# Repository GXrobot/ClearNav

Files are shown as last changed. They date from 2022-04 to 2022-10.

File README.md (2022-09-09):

GitHub Repository for Capstone Project of ClearNav Team
```
Members Include:
Spencer Lall
William Xue
Muhammad Ahmed Ather
William Huong
Namsakhi Kumar
Taimoor Ahmed
```

Spring - Summer 2022 Engineering Science Capstone Project

EZhud is a convenient heads up display motorcycle riders that features
built-in navigation, speed limit display and helmet mounted dashcam.

In this repository contains the code for the webserver, raspberry pi internal scripts
3D printed designs and GPS tracking code. 

EZhud is easy to use and and presents a simple interface for the user. Any information is presented in a heads up display above the riders right eye.

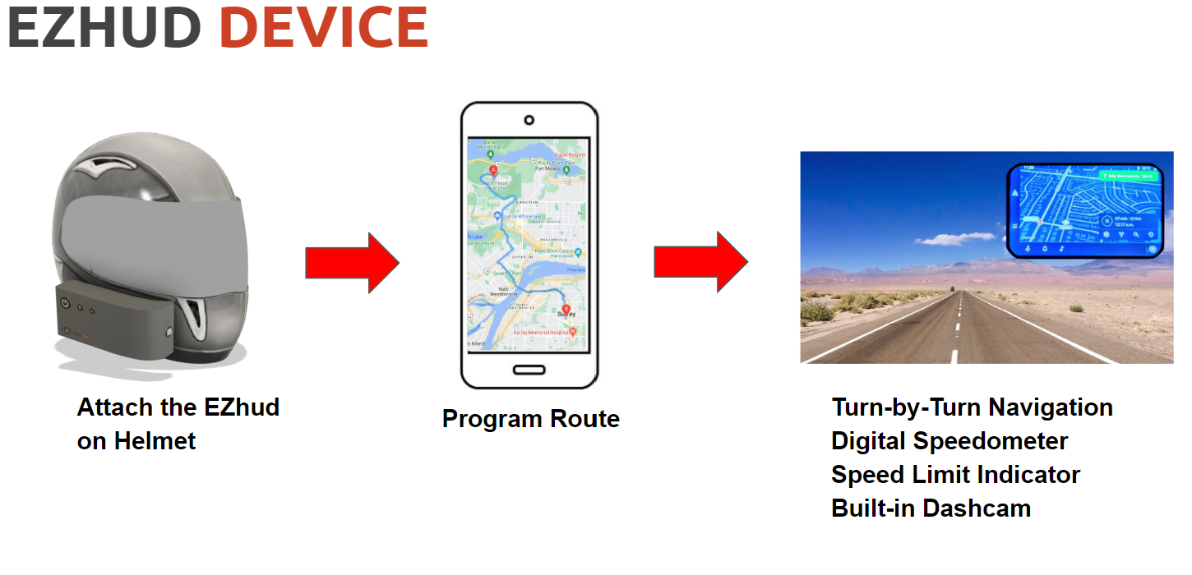
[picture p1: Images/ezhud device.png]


The following image shows the system overview of the EZhud device.

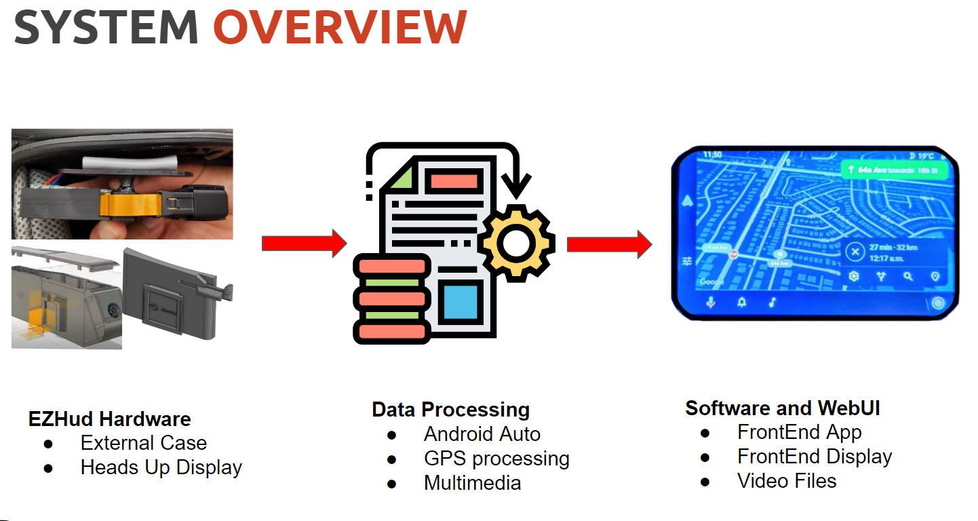
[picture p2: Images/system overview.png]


Here is a final product image on a full-face helmet.

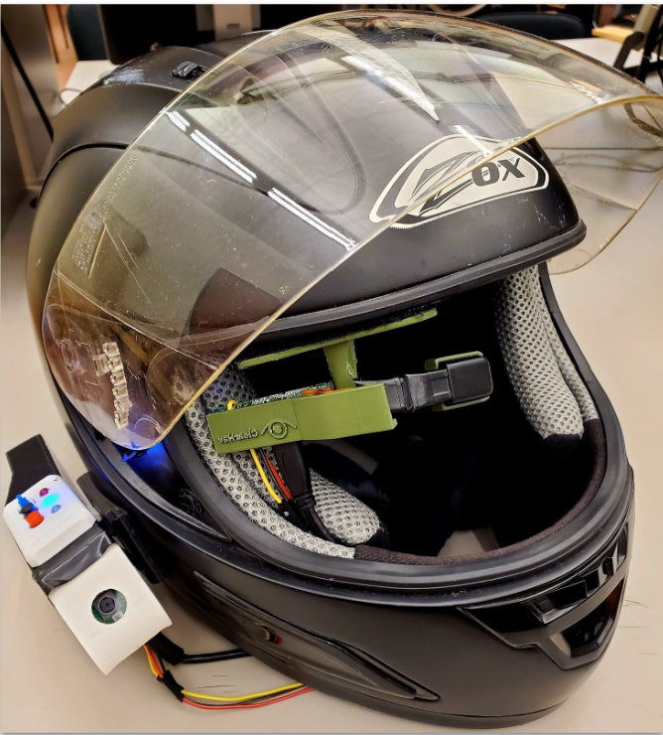
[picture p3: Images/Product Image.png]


The following is the Youtube video of the project.

IMAGE ALT TEXT HERE (https://www.youtube.com/watch?v=_HTLBEL7PS4)

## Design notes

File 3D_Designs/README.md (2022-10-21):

This folder contains all the 3D design in the EZhud project

Lead by: William Xue

- Vufine Holder (Balljoint Top.step)
```
Contains a 2 part design, main part attached to the upper lip of the helmet, 
display part attached with a ball joint to the main part. This allows the user to 
adjust the display angle of the device
```
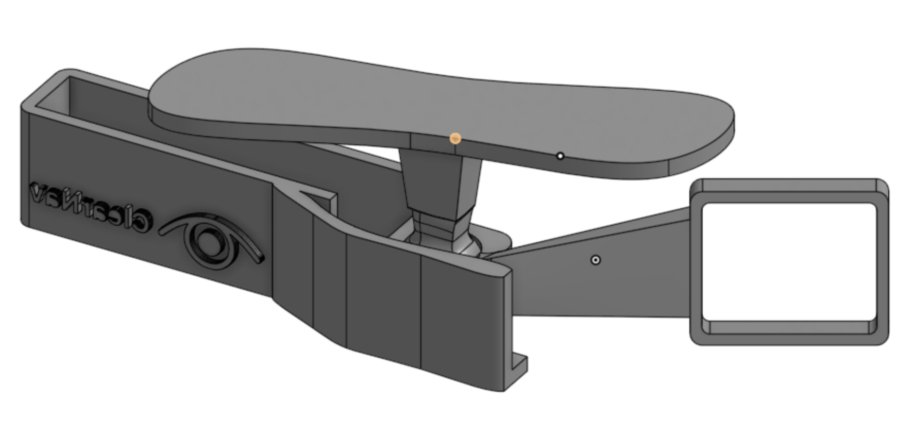
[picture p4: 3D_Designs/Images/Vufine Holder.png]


- Main Body (Body Design v166.step)
```
Contains the main body of the device, including the dashcam, battery, raspberry pi cm4 board and the GPS
a powerboost (DC-DC boost) is also included
```
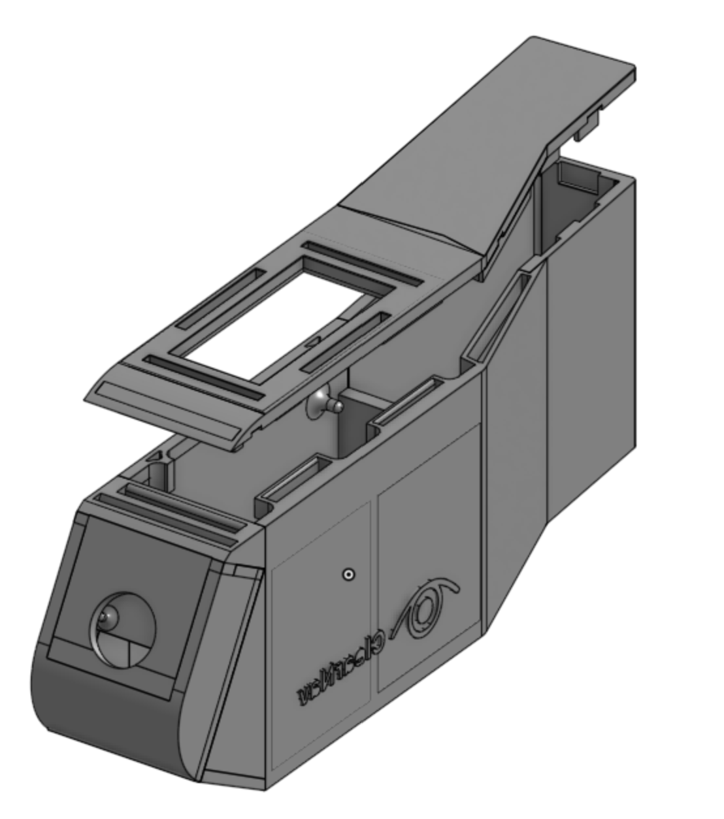
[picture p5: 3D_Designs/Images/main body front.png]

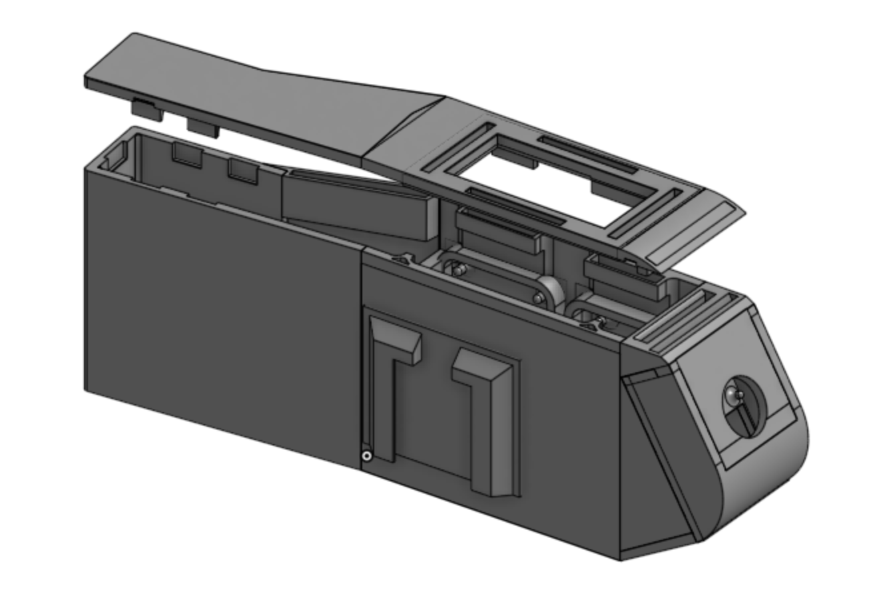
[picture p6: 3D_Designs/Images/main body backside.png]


- Helmet Attach V2 (HelmetAttachV2.step)
```
The concave side connects to the helmet via 3M VHB (very high bond tape), and the other side attaches to the main body
A locking pin is also included to keep the main body in place.
Attaches to majority of full face helmets as well as half face helmets
```

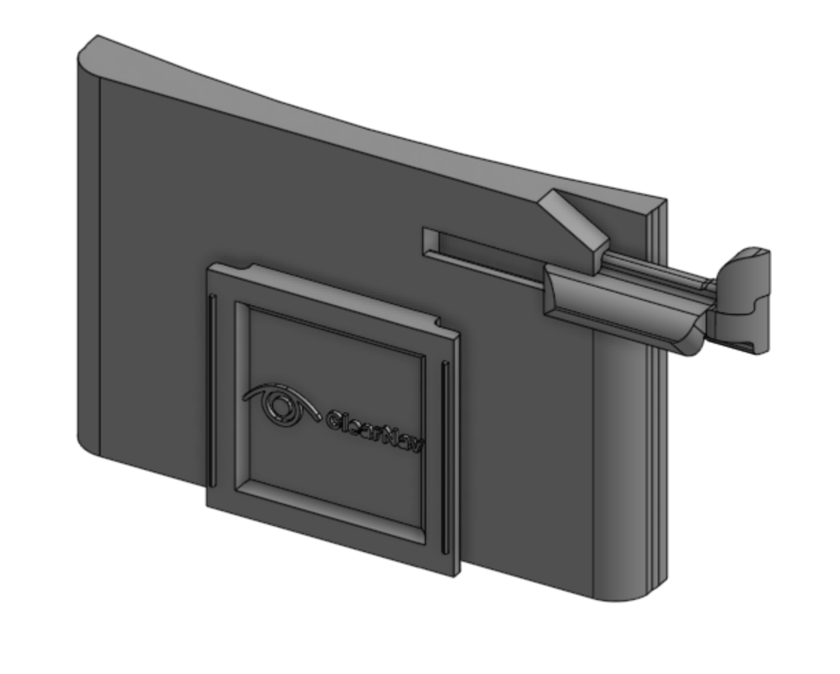
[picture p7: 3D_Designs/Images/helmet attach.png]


- Button Board (Button Board.step)
```
The board contains a cover for tactile switches and latching switches, the main interface to our device.
```

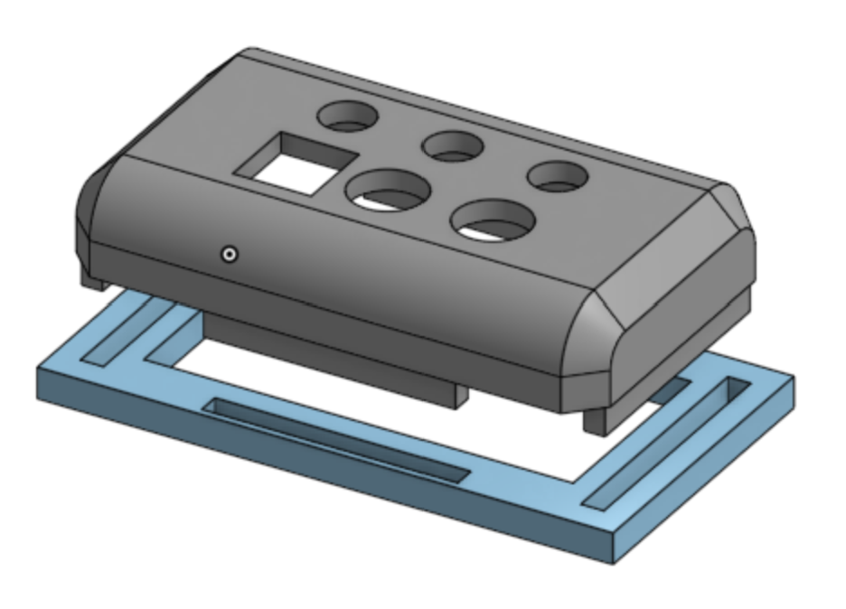
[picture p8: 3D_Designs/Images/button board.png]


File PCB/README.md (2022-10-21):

PCB Design for EZhud Motorcycle Project

```
Lead by:
Muhammad Ahmed Ather
Taimoor Ahmed
```

PCB design is compact and meant to be connected to the Raspberry Pi CM4 board, featuring
all the ports necessary for our project. Including RPi CM4 Hirose connectors, high speed USB,
SD card slot, GPIO connectors, mini-HDMI connector, USB-C power connector and the RPi Cam
interface

Work is still in progress! PCB still needs some tweaking to be fully functional. 

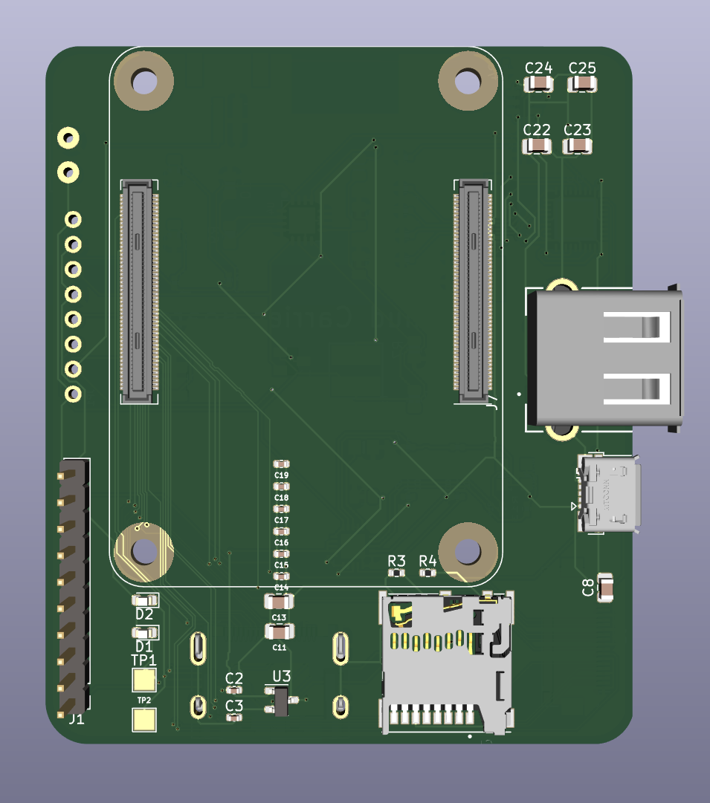
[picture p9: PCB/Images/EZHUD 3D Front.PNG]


This image shows the front of the PCB design.

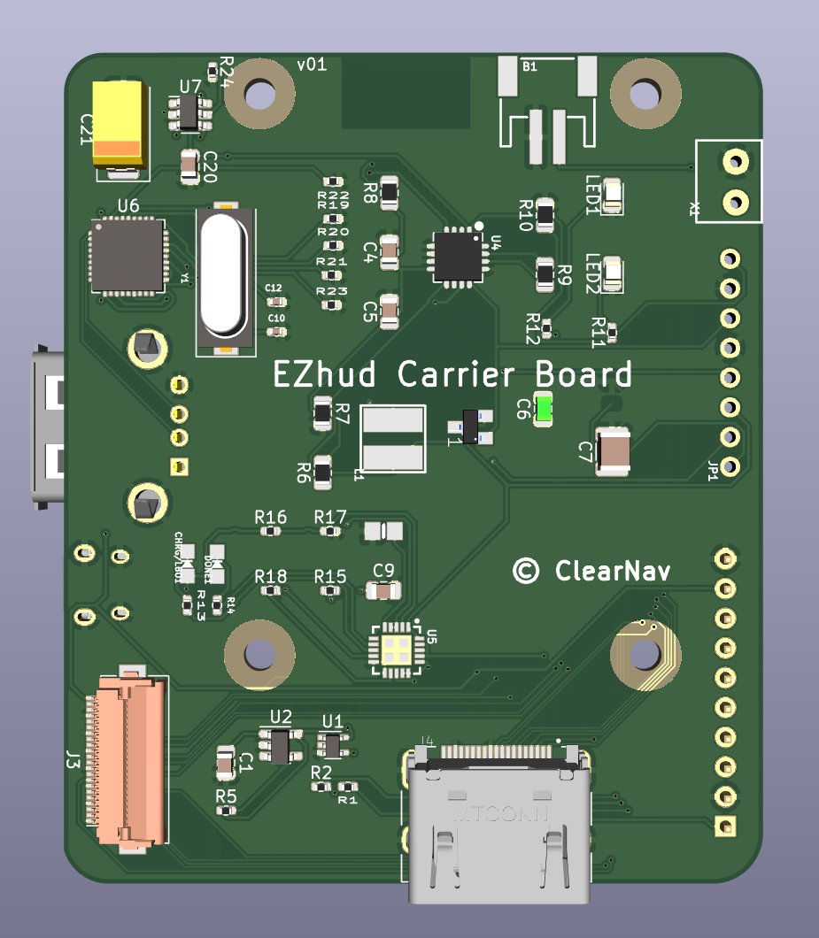
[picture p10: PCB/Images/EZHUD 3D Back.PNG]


This image shows the back of the PCB design.

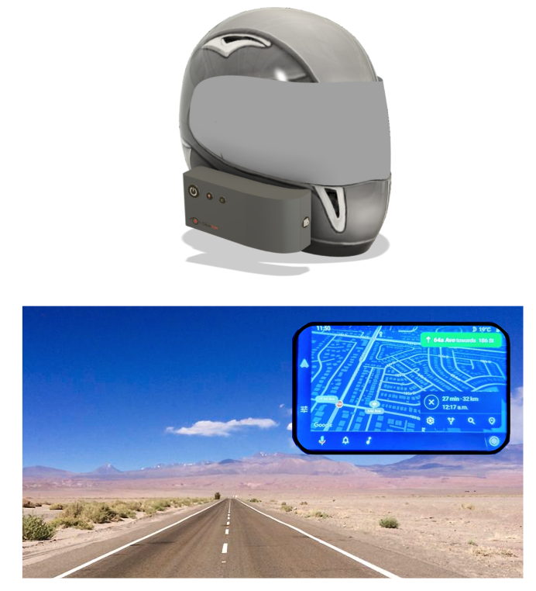
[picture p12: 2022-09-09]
Images/the solution.png

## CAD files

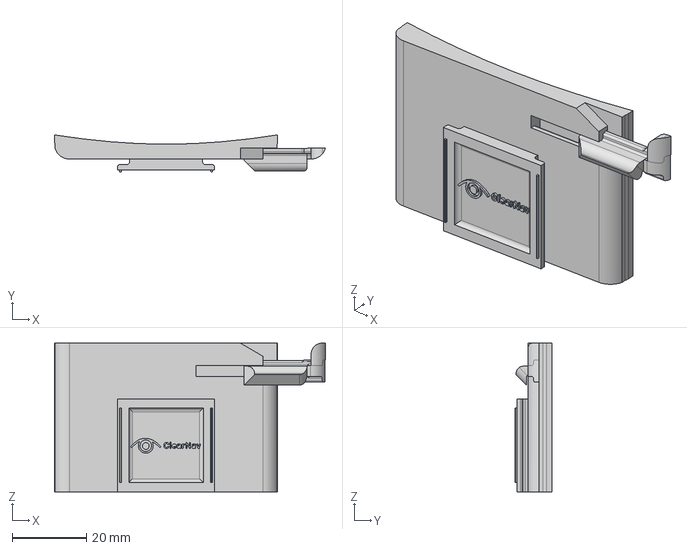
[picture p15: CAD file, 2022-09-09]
3D_Designs/HelmetAttachV2.step
72.9 x 10.0 x 40.0 mm

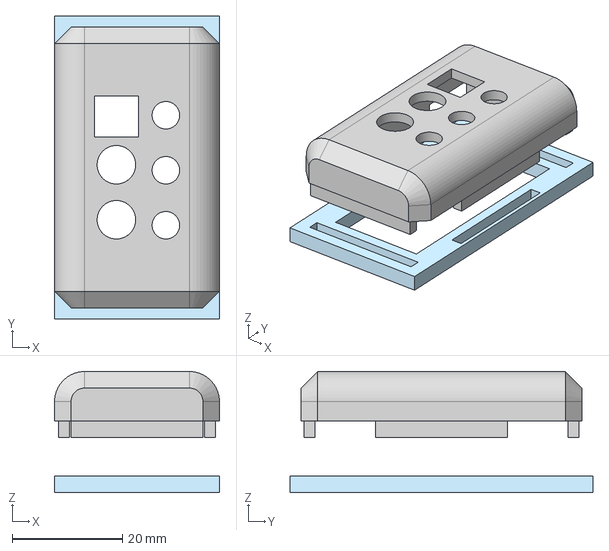
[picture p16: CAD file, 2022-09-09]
3D_Designs/Button Board.step
30.0 x 55.0 x 22.0 mm

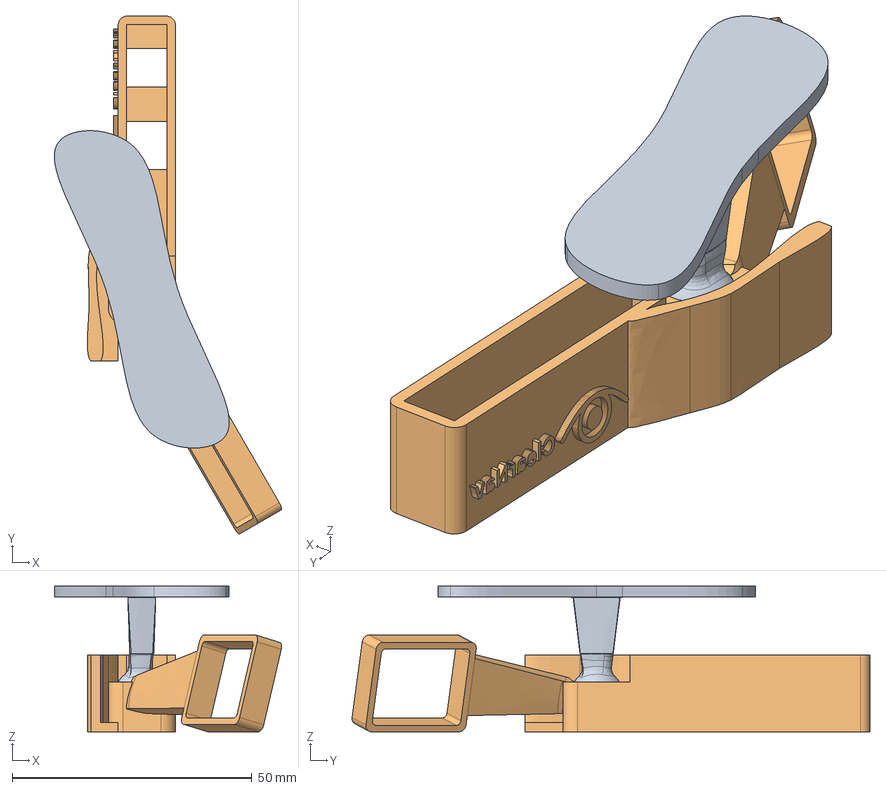
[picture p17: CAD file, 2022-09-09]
3D_Designs/Balljoint Top.step
47.4 x 107.9 x 30.4 mm

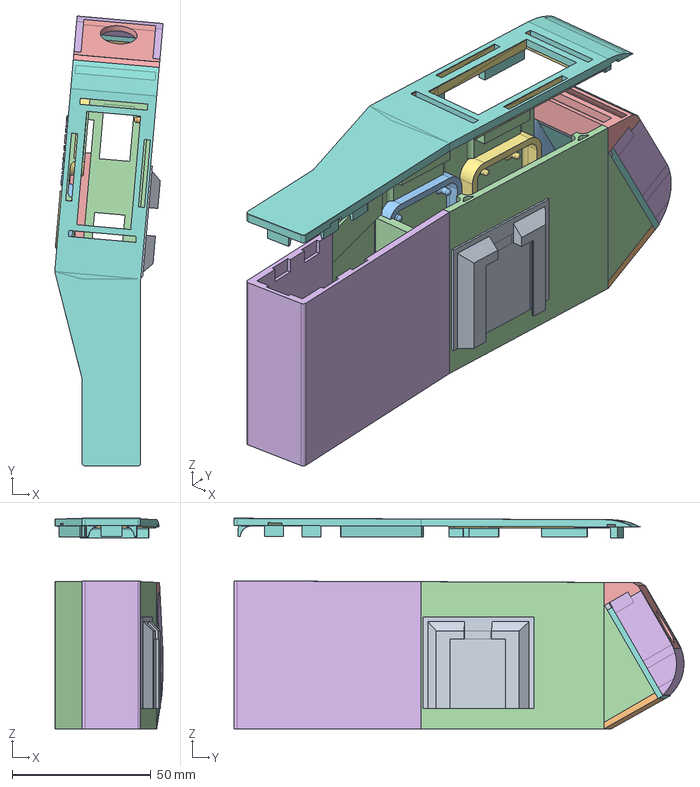
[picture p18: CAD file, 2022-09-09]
3D_Designs/Body Design v166.step
39.0 x 162.1 x 75.9 mm
Device Connector
CM4 Holder In Design
GPS Holder
Battery - CM4 Connector
Camera Holder
Powerboost Holder in Design
Camera Holder_1
Battery Holder
Button Board Bottom
Logo

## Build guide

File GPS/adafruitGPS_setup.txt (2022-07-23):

# upgrade packages
sudo apt update
sudo apt upgrade

# disable serial input/output interface
sudo raspi-config
--> disable login shell over serial
--> enable serial port hardware

# install adafruit gps python libary
pip3 install adafruit-circuitpython-gps

# get internet on pi
sudo iwlist wlan0 scan
sudo vim /etc/wpa_supplicant/wpa_supplicant.conf:

    ctrl_interface=DIR=/var/run/wpa_supplicant GROUP=netdev
    update_config=1
    country=CA

    network={
        ssid="You SSID Name"
        psk="Your WiFI Password"
        key_mgmt=WPA-PSK
    }

note: can view wpa_supplicant log messages using
    * sudo wpa_supplicant -c/etc/wpa_supplicant/wpa_supplicant.conf -iwlan0 -d

# install PySimpleGUI
pip3 install PySimpleGUI

# install tkinter
    --> note for mac (need to configure python 3 for tk): brew install python3-tk@3.9

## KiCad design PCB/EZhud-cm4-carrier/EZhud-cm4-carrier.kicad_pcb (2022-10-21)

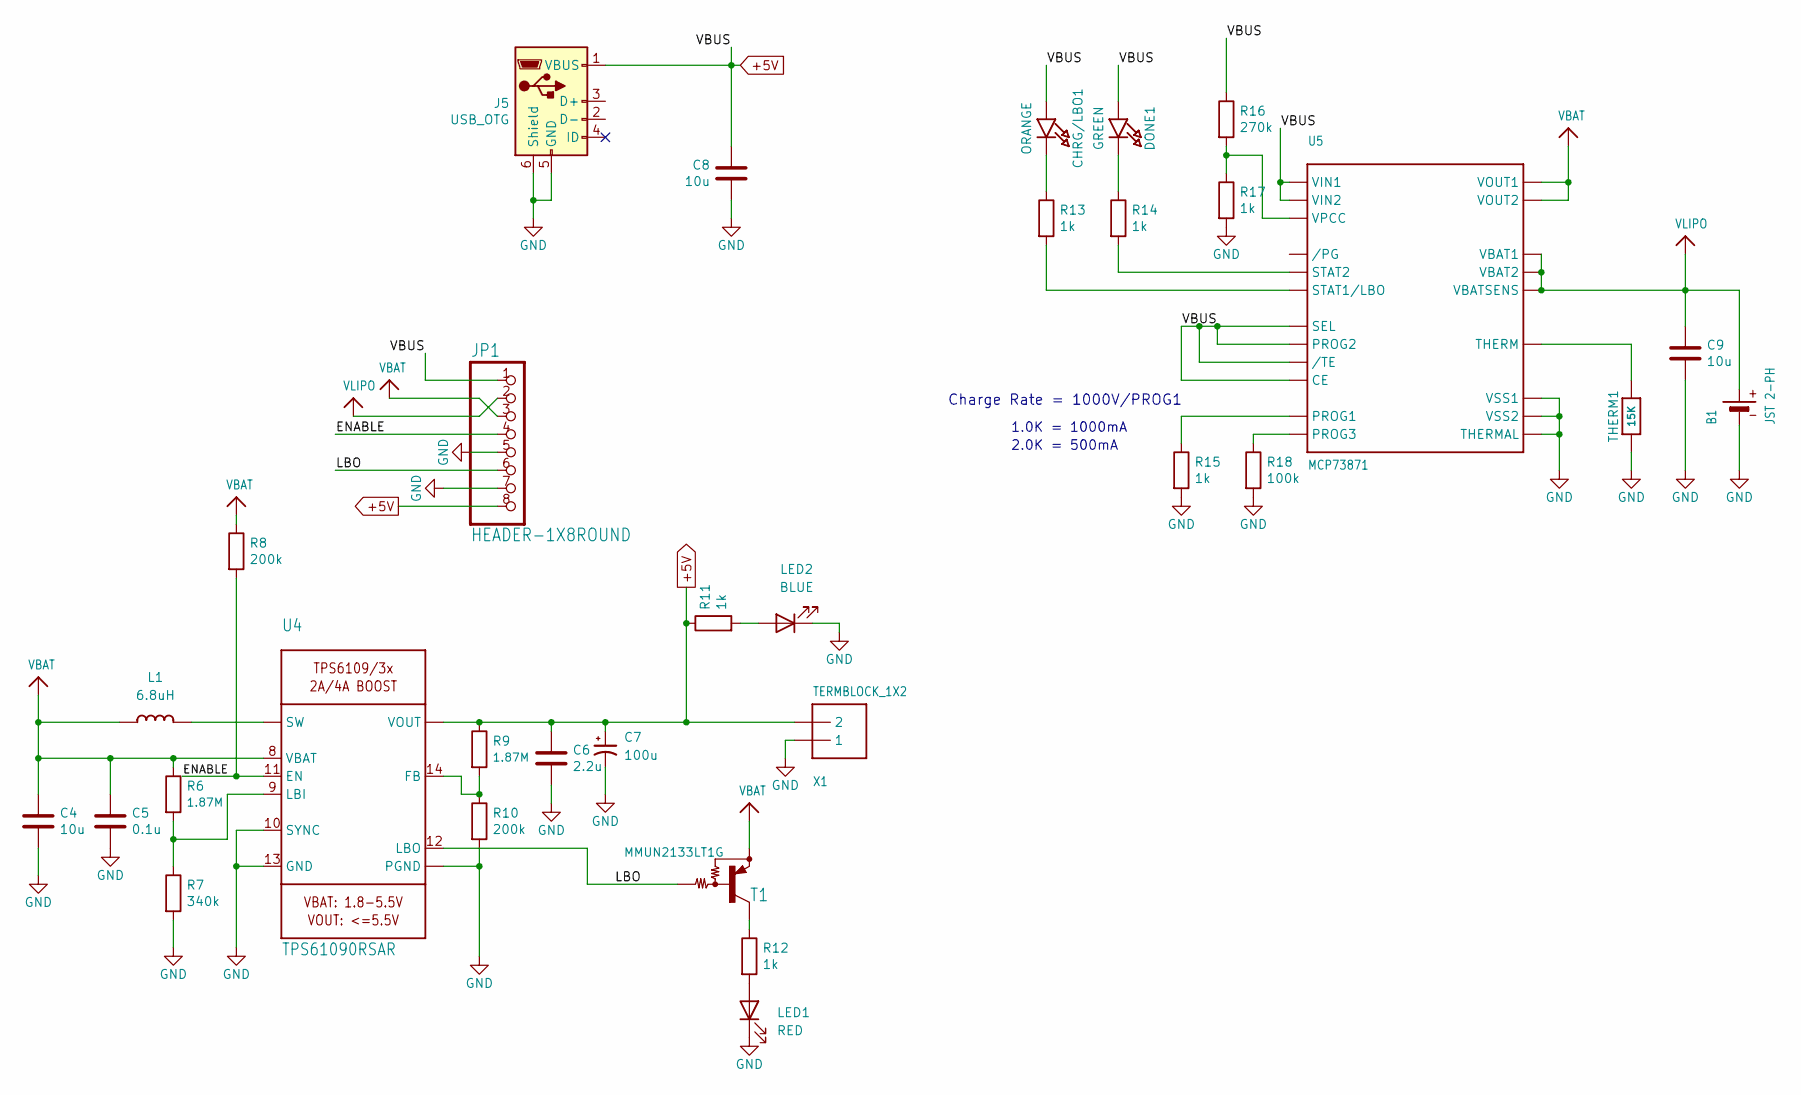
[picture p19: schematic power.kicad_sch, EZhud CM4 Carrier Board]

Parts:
B1: JST 2-PH; JSTPH2
C4, C8, C9: 10u; C_0805_2012Metric; Part Description 10uF 10% 10V Ceramic Capacitor X7R 0805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
C5: 0.1u; C_0805_2012Metric; Part Description 10uF 10% 10V Ceramic Capacitor X7R 0805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
C6: 2.2u; C_0805_2012Metric; Part Description 10uF 10% 10V Ceramic Capacitor X7R 0805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
C7: 100u; C_1210_3225Metric
CHRG/LBO1: ORANGE; CHIPLED_0805_NOOUTLINE
DONE1: GREEN; CHIPLED_0805_NOOUTLINE
J5: USB_OTG; USB_Micro-B_EDAC_UCON00686; Part Description USB - micro B USB 2.0 Receptacle Connec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
JP1: HEADER-1X8ROUND; 1X08_ROUND
L1: 6.8uH; INDUCTOR_5X5MM_TDK_VLC5045
LED1: RED; LED_0805_2012Metric
LED2: BLUE; LED_0805_2012Metric
R6, R9: 1.87M; R_0805_2012Metric
R7: 340k; R_0805_2012Metric
R8, R10: 200k; R_0805_2012Metric
R11, R12, R13, R14, R15, R17: 1k; R_0402_1005Metric; Part Description Resistor 1K M1005 1% 63mW
R16: 270k; R_0402_1005Metric; Part Description Resistor 1K M1005 1% 63mW
R18: 100k; R_0402_1005Metric; Part Description Resistor 1K M1005 1% 63mW
T1: MMUN2133LT1G; SC59-BEC
THERM1: 15K; 0805-NO
U4: TPS61090RSAR; PVQFN-16
U5: MCP73871; QFN20_4MM
X1: TERMBLOCK_1X2; TERMBLOCK_1X2-3.5MM

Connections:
+5V: C6.1, C7.1, C8.1, CHRG/LBO1.A, DONE1.A, J5.1 (VBUS), JP1.1, JP1.8, R9.1, R11.1, R16.1, U4.1 (VOUT), U4.15 (VOUT), U4.16 (VOUT), U5.P$3 (SEL), U5.P$4 (PROG2), U5.P$9 (/TE), U5.P$17 (CE), U5.P$18 (VIN1), U5.P$19 (VIN2), X1.2; also elsewhere on the board
/Power Boost/ENABLE: JP1.4, R8.2, U4.11 (EN)
/Power Boost/LBO: JP1.6, T1.B, U4.12 (LBO)
GND: B1.1 (-), C4.2, C5.2, C6.2, C7.2, C8.2, C9.2, J5.5 (GND), J5.6 (Shield), JP1.5, JP1.7, LED1.1 (K), LED2.1 (K), R7.2, R10.2, R15.2, R17.2, R18.2, THERM1.1, U4.5 (PGND), U4.6 (PGND), U4.7 (PGND), U4.10 (SYNC), U4.13 (GND), U4.P$18 (PGND), U4.P$19 (PGND), U4.P$20 (PGND), U4.P$21 (PGND), U4.P$22 (PGND), U4.THERMAL (PGND), U5.P$10 (VSS1), U5.P$11 (VSS2), U5.P$21 (THERMAL), X1.1; also elsewhere on the board
unnamed: CHRG/LBO1.C, R13.1
unnamed: DONE1.C, R14.1
unnamed: L1.P$2 (2), U4.3 (SW), U4.4 (SW)
unnamed: LED1.2 (A), R12.2
unnamed: LED2.2 (A), R11.2
unnamed: R6.2, R7.1, U4.9 (LBI)
unnamed: R9.2, R10.1, U4.14 (FB)
unnamed: R12.1, T1.C
unnamed: R13.2, U5.P$8 (STAT1/LBO)
unnamed: R14.2, U5.P$7 (STAT2)
unnamed: R15.1, U5.P$13 (PROG1)
unnamed: R16.2, R17.1, U5.P$2 (VPCC)
unnamed: R18.1, U5.P$12 (PROG3)
unnamed: THERM1.2, U5.P$5 (THERM)
VBAT: C4.1, C5.1, JP1.3, L1.P$1 (1), R6.1, R8.1, T1.E, U4.8 (VBAT), U5.P$1 (VOUT1), U5.P$20 (VOUT2)
VLIPO: B1.2 (+), C9.1, JP1.2, U5.P$14 (VBAT1), U5.P$15 (VBAT2), U5.P$16 (VBATSENS)

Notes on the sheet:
2.0K = 500mA
Charge Rate = 1000V/PROG1
1.0K = 1000mA

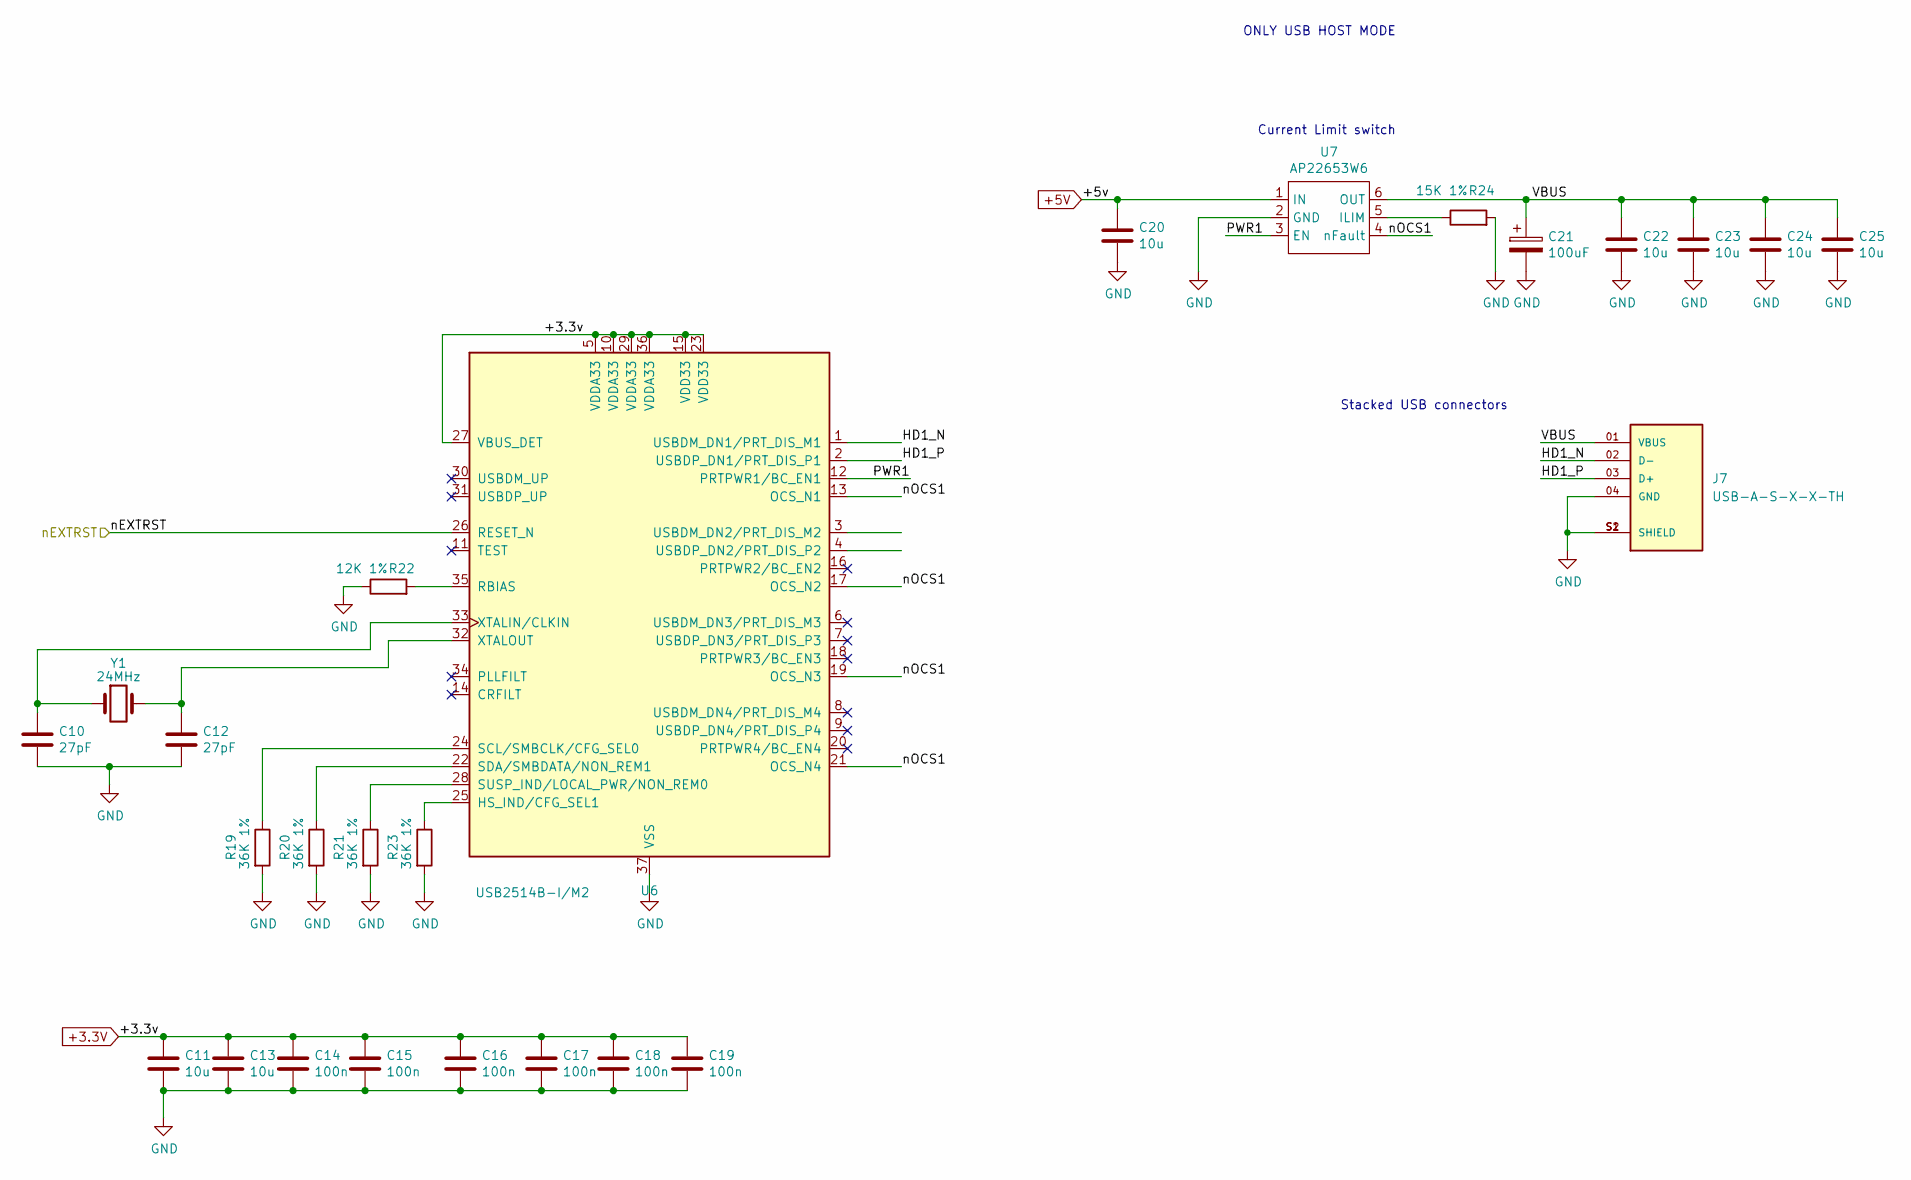
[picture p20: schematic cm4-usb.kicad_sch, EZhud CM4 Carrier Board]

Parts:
C10, C12: 27pF; C_0402_1005Metric; Part Description 27pF 5% 50V Ceramic Capacitor C0G, NP0 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
C11, C13, C20, C22, C23, C24, C25: 10u; C_0805_2012Metric; Part Description 10uF 10% 10V Ceramic Capacitor X7R 0805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
C14, C15, C16, C17, C18, C19: 100n; C_0402_1005Metric; Part Description 0.1uF 10% 16V Ceramic Capacitor X7R 040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
C21: 100uF; CP_EIA-7343-31_Kemet-D; Part Description Capacitor, SP-Cap, 100u, 6.3V, 15mR ESR
J7: USB-A-S-X-X-TH; SAMTEC_USB-A-S-X-X-TH; PARTREV R
R19, R20, R21, R23: 36K 1%; R_0402_1005Metric; Part Description Resistor 36K M1005 1% 63mW
R22: 12K 1%; R_0402_1005Metric; Part Description Resistor 12K M1005 1% 63mW
R24: 15K 1%; R_0402_1005Metric; Part Description Resistor 15K M1005 1% 63mW
U6: USB2514B-I/M2; QFN-36-1EP_6x6mm_P0.5mm_EP3.7x3.7mm; Part Description USB Hub Controller USB Interface 36-SQF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
U7: AP22653W6; SOT-23-6; Part Description Power Switch/Driver 1:1 P-Channel 2.1A 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
Y1: 24MHz; Crystal_SMD_HC49-SD; Part Description 24MHz Crystal 18pf 30ppm 30ppm

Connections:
+3.3V: C11.1, C13.1, C14.1, C15.1, C16.1, C17.1, C18.1, C19.1, U6.5 (VDDA33), U6.10 (VDDA33), U6.15 (VDD33), U6.23 (VDD33), U6.27 (VBUS_DET), U6.29 (VDDA33), U6.36 (VDDA33); also elsewhere on the board
+5V: C20.1, U7.1 (IN); also elsewhere on the board
/CM4 USB/HD1_N: J7.02 (D-), U6.1 (USBDM_DN1/PRT_DIS_M1)
/CM4 USB/HD1_P: J7.03 (D+), U6.2 (USBDP_DN1/PRT_DIS_P1)
/CM4 USB/PWR1: U6.12 (PRTPWR1/BC_EN1), U7.3 (EN)
/CM4 USB/VBUS: C21.1, C22.1, C23.1, C24.1, C25.1, J7.01 (VBUS), U7.6 (OUT)
/CM4 USB/nEXTRST: U6.26 (RESET_N)
/CM4 USB/nOCS1: U6.13 (OCS_N1), U6.17 (OCS_N2), U6.19 (OCS_N3), U6.21 (OCS_N4), U7.4 (nFault)
GND: C10.2, C11.2, C12.2, C13.2, C14.2, C15.2, C16.2, C17.2, C18.2, C19.2, C20.2, C21.2, C22.2, C23.2, C24.2, C25.2, J7.04 (GND), J7.S1 (SHIELD), J7.S2 (SHIELD), R19.2, R20.2, R21.2, R22.1, R23.2, R24.2, U6.37 (VSS), U7.2 (GND); also elsewhere on the board
unnamed: C10.1, U6.33 (XTALIN/CLKIN), Y1.1
unnamed: C12.1, U6.32 (XTALOUT), Y1.2
unnamed: R19.1, U6.24 (SCL/SMBCLK/CFG_SEL0)
unnamed: R20.1, U6.22 (SDA/SMBDATA/NON_REM1)
unnamed: R21.1, U6.28 (SUSP_IND/LOCAL_PWR/NON_REM0)
unnamed: R22.2, U6.35 (RBIAS)
unnamed: R23.1, U6.25 (HS_IND/CFG_SEL1)
unnamed: R24.1, U7.5 (ILIM)

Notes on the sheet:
Current Limit switch
Stacked USB connectors
ONLY USB HOST MODE

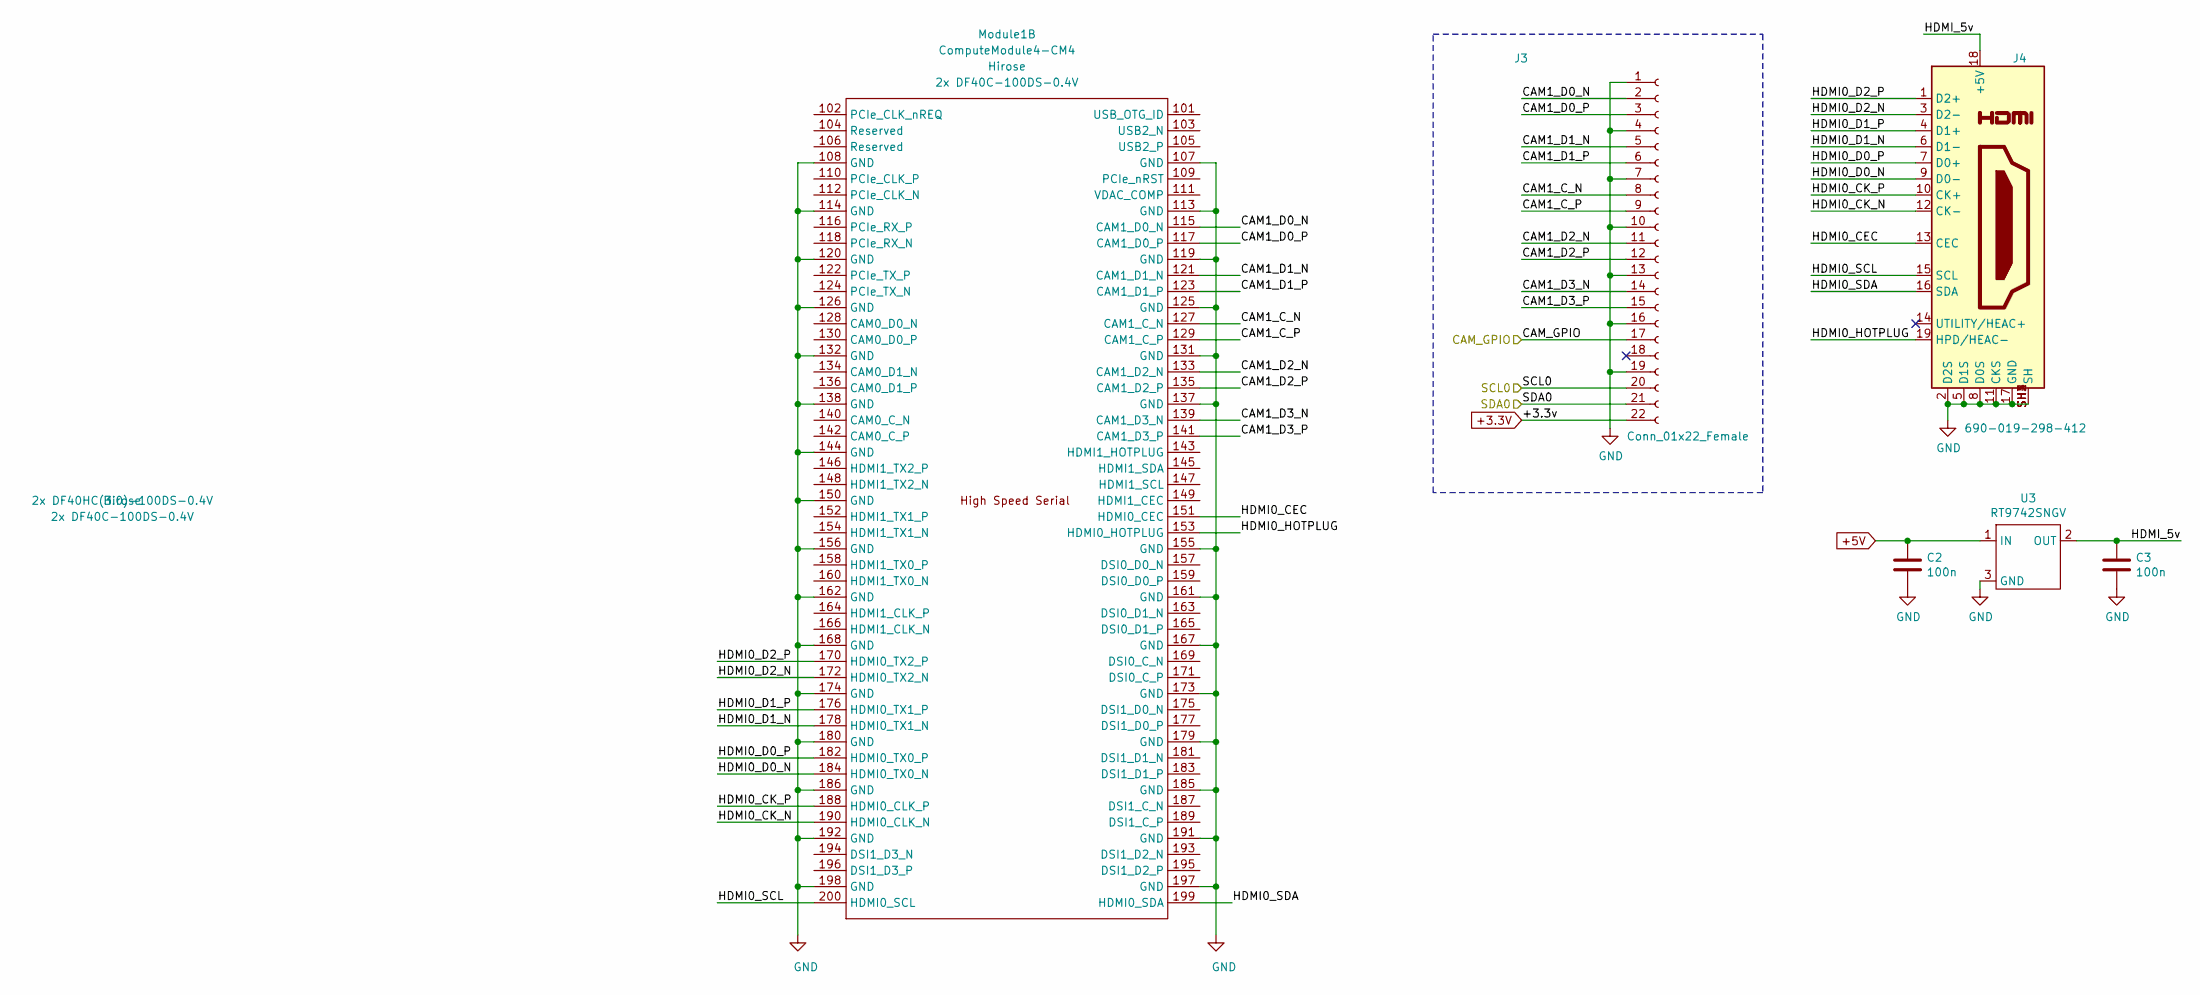
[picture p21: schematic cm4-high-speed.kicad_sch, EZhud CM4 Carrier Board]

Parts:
C2, C3: 100n; C_0402_1005Metric; Part Description 0.1uF 10% 16V Ceramic Capacitor X7R 040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
J3: Conn_01x22_Female; Hirose_FH12-22S-0.5SH_1x22-1MP_P0.50mm_Horizontal; Part Description 22 Position FFC, FPC Connector Contacts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
J4: 690-019-298-412; EDAC 690-019-298-412; Part Description HDMI Connector, Right Angle, 19 Contact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
Module1: ComputeModule4-CM4; Raspberry-Pi-4-Compute-Module; MPN 2x DF40C-100DS-0.4V; Digi-Key_PN 2x H11615CT-ND
U3: RT9742SNGV; SOT-23; Part Description Power Switch/Driver 1:1 N-Channel 500mA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

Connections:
+3.3V: J3.22; also elsewhere on the board
+5V: C2.1, U3.1 (IN); also elsewhere on the board
/CM4 High Speed/CAM1_C_N: J3.8, Module1.127 (CAM1_C_N)
/CM4 High Speed/CAM1_C_P: J3.9, Module1.129 (CAM1_C_P)
/CM4 High Speed/CAM1_D0_N: J3.2, Module1.115 (CAM1_D0_N)
/CM4 High Speed/CAM1_D0_P: J3.3, Module1.117 (CAM1_D0_P)
/CM4 High Speed/CAM1_D1_N: J3.5, Module1.121 (CAM1_D1_N)
/CM4 High Speed/CAM1_D1_P: J3.6, Module1.123 (CAM1_D1_P)
/CM4 High Speed/CAM1_D2_N: J3.11, Module1.133 (CAM1_D2_N)
/CM4 High Speed/CAM1_D2_P: J3.12, Module1.135 (CAM1_D2_P)
/CM4 High Speed/CAM1_D3_N: J3.14, Module1.139 (CAM1_D3_N)
/CM4 High Speed/CAM1_D3_P: J3.15, Module1.141 (CAM1_D3_P)
/CM4 High Speed/CAM_GPIO: J3.17; also elsewhere on the board
/CM4 High Speed/HDMI0_CEC: J4.13 (CEC), Module1.151 (HDMI0_CEC)
/CM4 High Speed/HDMI0_CK_N: J4.12 (CK-), Module1.190 (HDMI0_CLK_N)
/CM4 High Speed/HDMI0_CK_P: J4.10 (CK+), Module1.188 (HDMI0_CLK_P)
/CM4 High Speed/HDMI0_D0_N: J4.9 (D0-), Module1.184 (HDMI0_TX0_N)
/CM4 High Speed/HDMI0_D0_P: J4.7 (D0+), Module1.182 (HDMI0_TX0_P)
/CM4 High Speed/HDMI0_D1_N: J4.6 (D1-), Module1.178 (HDMI0_TX1_N)
/CM4 High Speed/HDMI0_D1_P: J4.4 (D1+), Module1.176 (HDMI0_TX1_P)
/CM4 High Speed/HDMI0_D2_N: J4.3 (D2-), Module1.172 (HDMI0_TX2_N)
/CM4 High Speed/HDMI0_D2_P: J4.1 (D2+), Module1.170 (HDMI0_TX2_P)
/CM4 High Speed/HDMI0_HOTPLUG: J4.19 (HPD/HEAC-), Module1.153 (HDMI0_HOTPLUG)
/CM4 High Speed/HDMI0_SCL: J4.15 (SCL), Module1.200 (HDMI0_SCL)
/CM4 High Speed/HDMI0_SDA: J4.16 (SDA), Module1.199 (HDMI0_SDA)
/CM4 High Speed/HDMI_5v: C3.1, J4.18 (+5V), U3.2 (OUT)
/CM4 High Speed/SCL0: J3.20; also elsewhere on the board
/CM4 High Speed/SDA0: J3.21; also elsewhere on the board
GND: C2.2, C3.2, J3.1, J3.4, J3.7, J3.10, J3.13, J3.16, J3.19, J4.2 (D2S), J4.5 (D1S), J4.8 (D0S), J4.11 (CKS), J4.17 (GND), J4.SH1 (SH), J4.SH2 (SH), J4.SH3 (SH), J4.SH4 (SH), Module1.107 (GND), Module1.108 (GND), Module1.113 (GND), Module1.114 (GND), Module1.119 (GND), Module1.120 (GND), Module1.125 (GND), Module1.126 (GND), Module1.131 (GND), Module1.132 (GND), Module1.137 (GND), Module1.138 (GND), Module1.144 (GND), Module1.150 (GND), Module1.155 (GND), Module1.156 (GND), Module1.161 (GND), Module1.162 (GND), Module1.167 (GND), Module1.168 (GND), Module1.173 (GND), Module1.174 (GND), Module1.179 (GND), Module1.180 (GND), Module1.185 (GND), Module1.186 (GND), Module1.191 (GND), Module1.192 (GND), Module1.197 (GND), Module1.198 (GND), U3.3 (GND); also elsewhere on the board

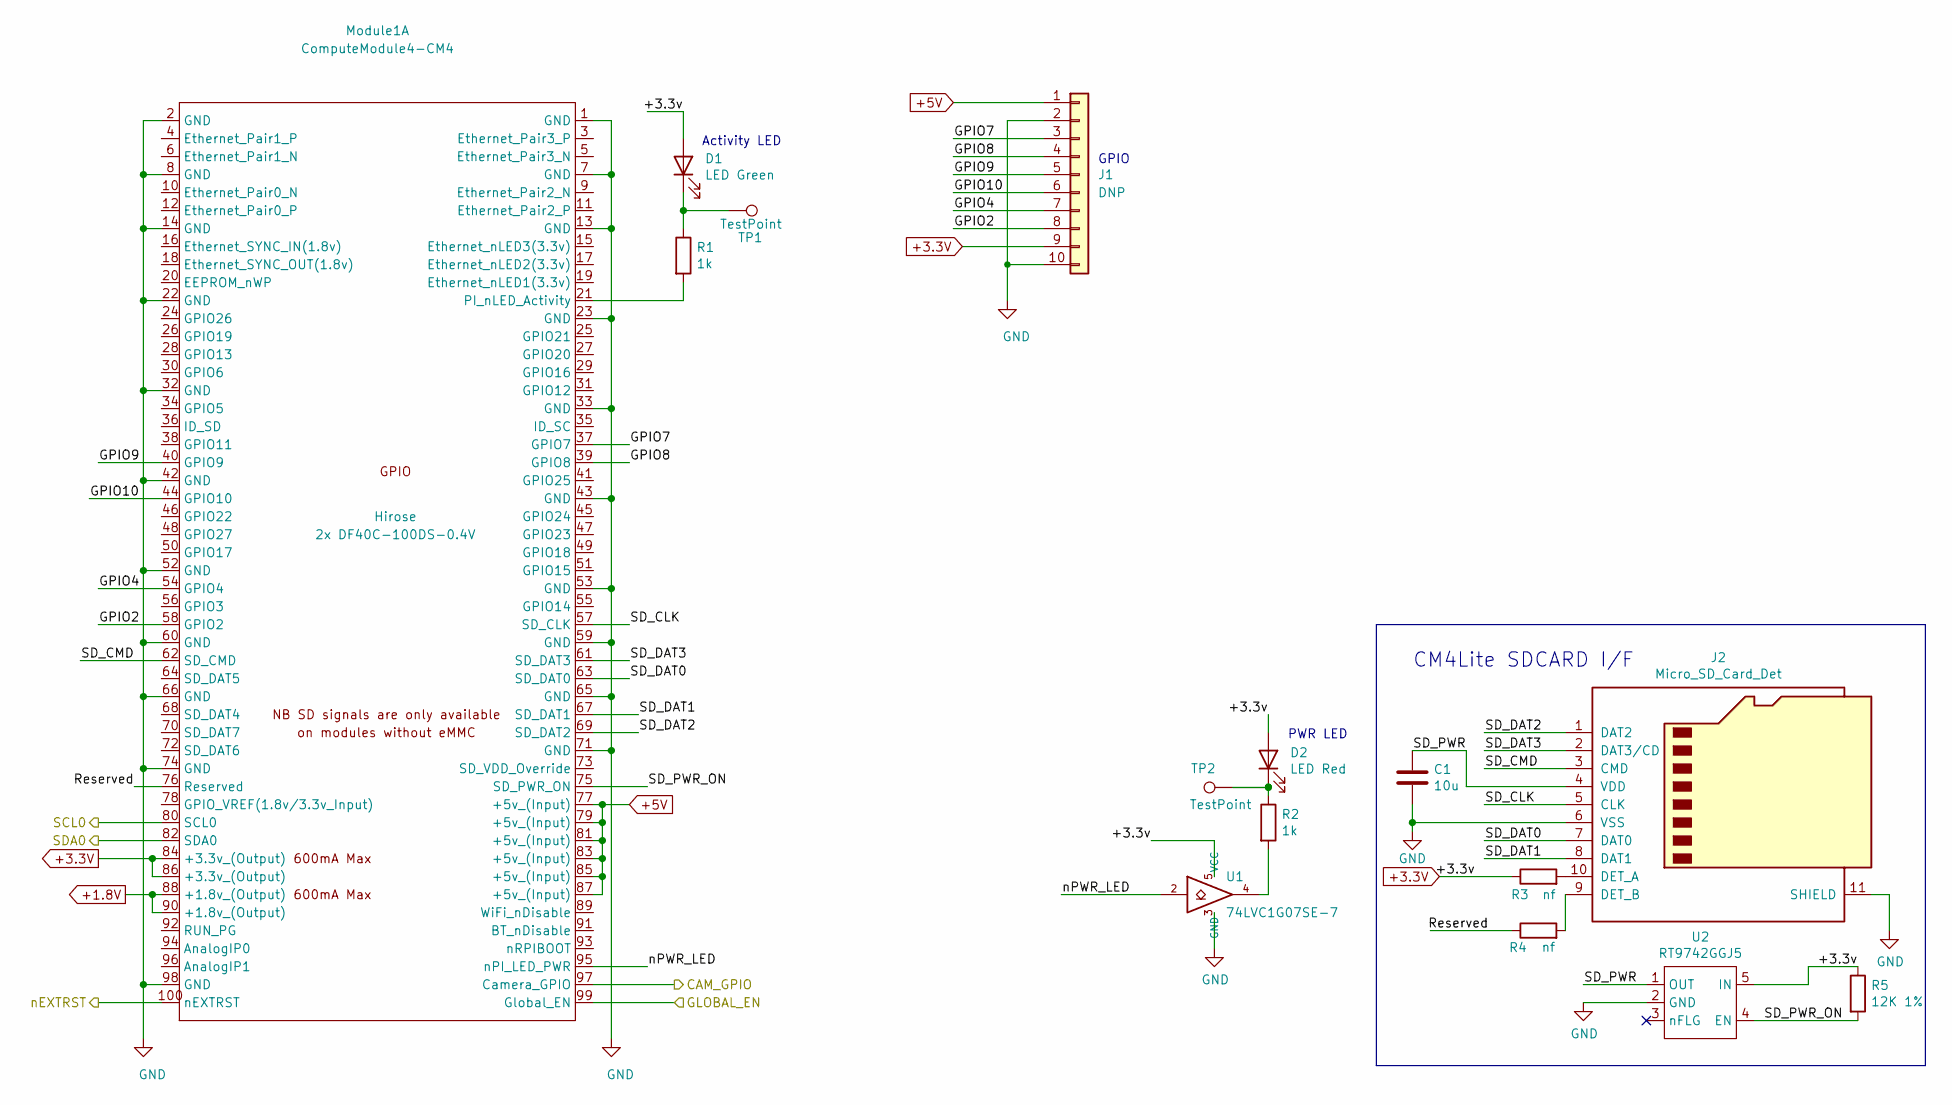
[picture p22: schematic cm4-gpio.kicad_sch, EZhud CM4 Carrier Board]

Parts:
C1: 10u; C_0805_2012Metric; Part Description 10uF 10% 10V Ceramic Capacitor X7R 0805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
D1: LED Green; LED_0603_1608Metric; Part Description Green 572nm LED Indication - Discrete 2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
D2: LED Red; LED_0603_1608Metric; Part Description Red 620nm LED Indication - Discrete 2.2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
J1: DNP; PinHeader_1x10_P2.54mm_Vertical
J2: Micro_SD_Card_Det; SDCARD_MOLEX_503398-1892; Part Description 9 (8 + 1) Position Card Connector micro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
Module1: ComputeModule4-CM4; Raspberry-Pi-4-Compute-Module; MPN 2x DF40C-100DS-0.4V; Digi-Key_PN 2x H11615CT-ND
R1, R2: 1k; R_0402_1005Metric; Part Description Resistor 1K M1005 1% 63mW
R3, R4: nf; R_0402_1005Metric; Part Description Resistor 1K M1005 1% 63mW
R5: 12K 1%; R_0402_1005Metric; Part Description Resistor 12K M1005 1% 63mW
TP1, TP2: TestPoint; TestPoint_Pad_2.0x2.0mm
U1: 74LVC1G07SE-7; SOT-353_SC-70-5; Part Description Buffer, Non-Inverting 1 Element 1 Bit p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
U2: RT9742GGJ5; SOT-23-5; Part Description Power Switch/Driver 1:1 N-Channel 1A TS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

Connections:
+1.8V: Module1.88 (+1.8v_(Output)), Module1.90 (+1.8v_(Output))
+3.3V: D1.2 (A), D2.2 (A), J1.9, Module1.84 (+3.3v_(Output)), Module1.86 (+3.3v_(Output)), R3.1, R5.1, U1.5 (VCC), U2.5 (IN); also elsewhere on the board
+5V: J1.1, Module1.77 (+5v_(Input)), Module1.79 (+5v_(Input)), Module1.81 (+5v_(Input)), Module1.83 (+5v_(Input)), Module1.85 (+5v_(Input)), Module1.87 (+5v_(Input)); also elsewhere on the board
/CM4 GPIO/GLOBAL_EN: Module1.99 (Global_EN)
/CM4 GPIO/GPIO2: J1.8, Module1.58 (GPIO2)
/CM4 GPIO/GPIO4: J1.7, Module1.54 (GPIO4)
/CM4 GPIO/GPIO7: J1.3, Module1.37 (GPIO7)
/CM4 GPIO/GPIO8: J1.4, Module1.39 (GPIO8)
/CM4 GPIO/GPIO9: J1.5, Module1.40 (GPIO9)
/CM4 GPIO/GPIO10: J1.6, Module1.44 (GPIO10)
/CM4 GPIO/Reserved: Module1.76 (Reserved), R4.1
/CM4 GPIO/SD_CLK: J2.5 (CLK), Module1.57 (SD_CLK)
/CM4 GPIO/SD_CMD: J2.3 (CMD), Module1.62 (SD_CMD)
/CM4 GPIO/SD_DAT0: J2.7 (DAT0), Module1.63 (SD_DAT0)
/CM4 GPIO/SD_DAT1: J2.8 (DAT1), Module1.67 (SD_DAT1)
/CM4 GPIO/SD_DAT2: J2.1 (DAT2), Module1.69 (SD_DAT2)
/CM4 GPIO/SD_DAT3: J2.2 (DAT3/CD), Module1.61 (SD_DAT3)
/CM4 GPIO/SD_PWR: C1.1, J2.4 (VDD), U2.1 (OUT)
/CM4 GPIO/SD_PWR_ON: Module1.75 (SD_PWR_ON), R5.2, U2.4 (EN)
/CM4 GPIO/nEXTRST: Module1.100 (nEXTRST)
/CM4 GPIO/nPWR_LED: Module1.95 (nPI_LED_PWR), U1.2
/CM4 High Speed/CAM_GPIO: Module1.97 (Camera_GPIO); also elsewhere on the board
/CM4 High Speed/SCL0: Module1.80 (SCL0); also elsewhere on the board
/CM4 High Speed/SDA0: Module1.82 (SDA0); also elsewhere on the board
GND: C1.2, J1.2, J1.10, J2.6 (VSS), J2.11 (SHIELD), Module1.1 (GND), Module1.2 (GND), Module1.7 (GND), Module1.8 (GND), Module1.13 (GND), Module1.14 (GND), Module1.22 (GND), Module1.23 (GND), Module1.32 (GND), Module1.33 (GND), Module1.42 (GND), Module1.43 (GND), Module1.52 (GND), Module1.53 (GND), Module1.59 (GND), Module1.60 (GND), Module1.65 (GND), Module1.66 (GND), Module1.71 (GND), Module1.74 (GND), Module1.98 (GND), U1.3 (GND), U2.2 (GND); also elsewhere on the board
unnamed: D1.1 (K), R1.1, TP1.1
unnamed: D2.1 (K), R2.1, TP2.1
unnamed: J2.9 (DET_B), R4.2
unnamed: J2.10 (DET_A), R3.2
unnamed: Module1.21 (PI_nLED_Activity), R1.2
unnamed: R2.2, U1.4

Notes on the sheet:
PWR LED
CM4Lite SDCARD I/F
Activity LED
GPIO

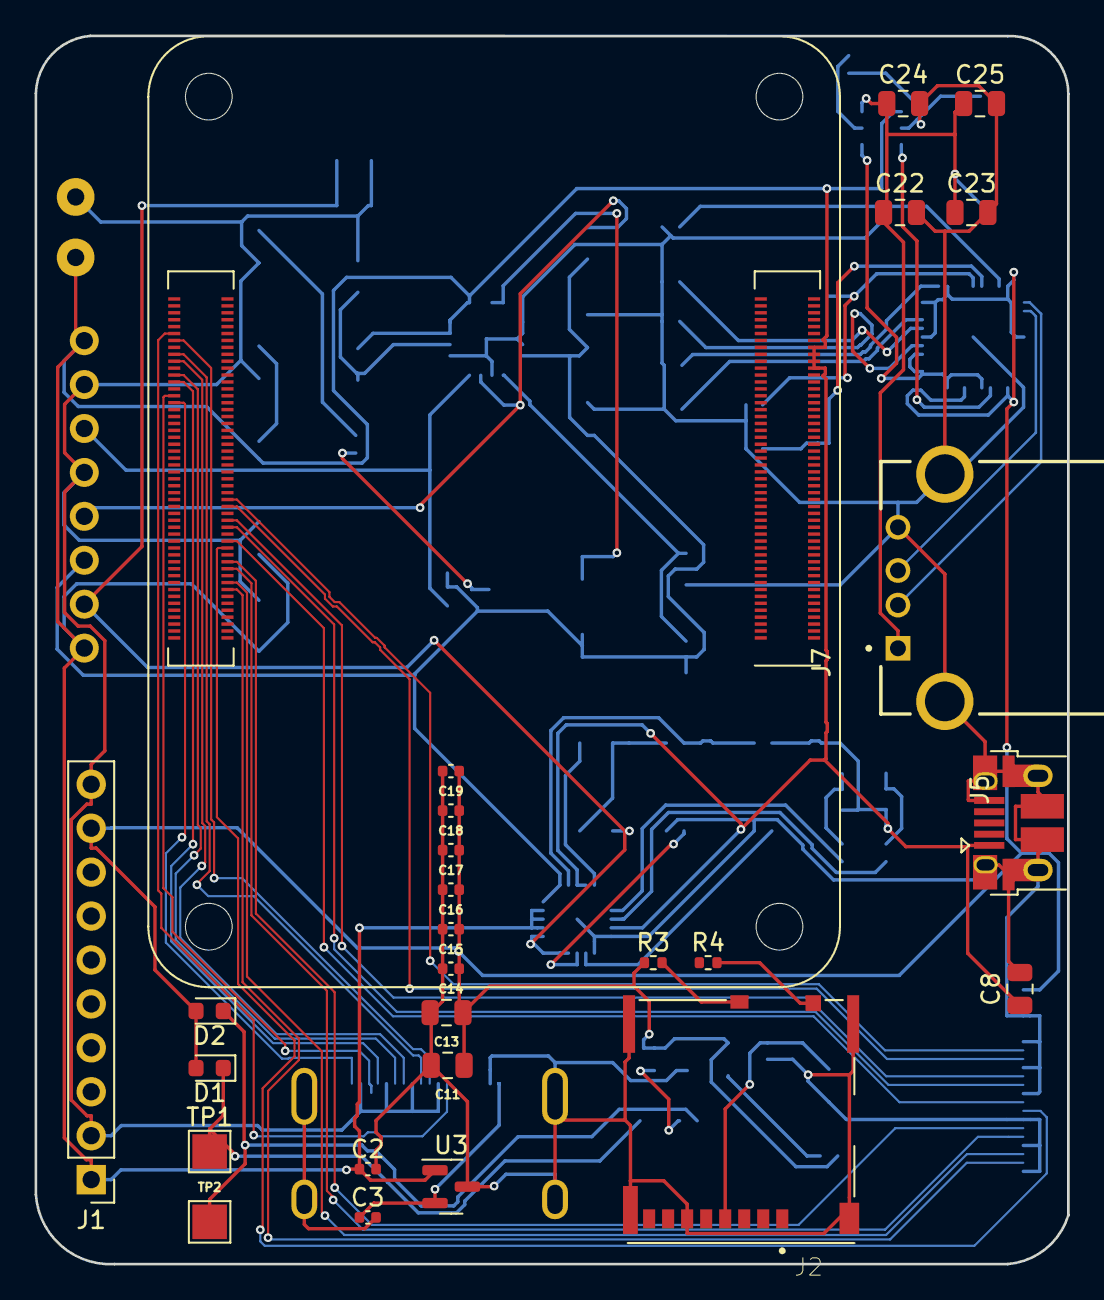
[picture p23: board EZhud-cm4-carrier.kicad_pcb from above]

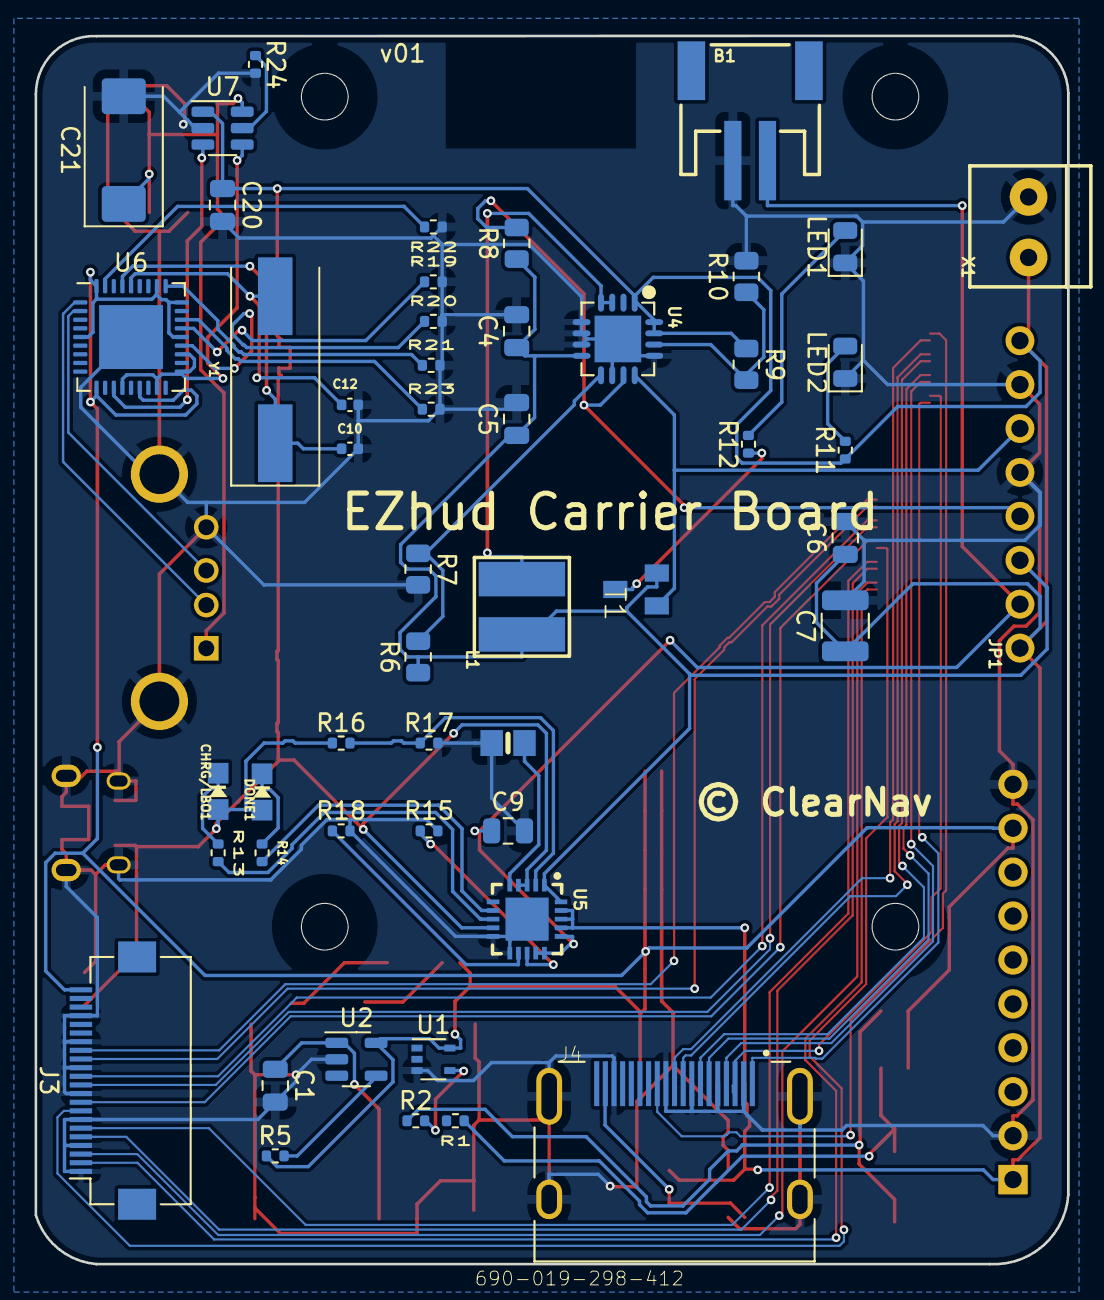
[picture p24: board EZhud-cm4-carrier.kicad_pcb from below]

Board: 2 copper layers, 59.7 x 71.0 mm, 78 parts (51 on the bottom side), 83 nets.

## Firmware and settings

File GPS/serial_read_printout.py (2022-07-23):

#!/usr/bin/env python3

# https://github.com/adafruit/Adafruit_CircuitPython_GPS/blob/main/examples/gps_simpletest.py
# read data through ttyUSB0 port
# print gps info at specified rate

import time
import serial
import adafruit_gps

uart = serial.Serial(
        # try ports ttyS0, ttyUSB0, ttyAMA0 if not working
        port='/dev/ttyUSB0',                # read/write sereal port
        baudrate = 9600,                    # data transfer: 9500 bits per second
        parity=serial.PARITY_NONE,          # no parity checking
        stopbits=serial.STOPBITS_ONE,       # indicates end of data transmission
        bytesize=serial.EIGHTBITS,          # number of data bits
        timeout=5                           # n seconds before timing out
)

gps = adafruit_gps.GPS(uart, debug=False)  # Use UART/pyserial

# Initialize the GPS module by changing what data it sends and at what rate.
# Turn on the basic GGA and RMC info (what you typically want)
gps.send_command(b"PMTK314,0,1,0,1,0,0,0,0,0,0,0,0,0,0,0,0,0,0,0")

# Set update rate to once a second (1hz)
gps.send_command(b"PMTK220,1000")

# Main loop
last_print = time.monotonic()
while True:

    # Every second print out current location details if there's a fix.
    gps.update()
    current = time.monotonic()
    if current - last_print >= 1.0:
        last_print = current

        # no fix yet
        if not gps.has_fix:
            print("Waiting for fix...")
            continue

        # parse raw GPS NMEA sentence
        print("=" * 40)  # Print a separator line.
        print(
            "Fix timestamp: {}/{}/{} {:02}:{:02}:{:02}".format(
                gps.timestamp_utc.tm_mon,  # Grab parts of the time from the
                gps.timestamp_utc.tm_mday,  # struct_time object that holds
                gps.timestamp_utc.tm_year,  # the fix time.  Note you might
                gps.timestamp_utc.tm_hour,  # not get all data like year, day,
                gps.timestamp_utc.tm_min,  # month!
                gps.timestamp_utc.tm_sec,
            )
        )
        print("Latitude: {0:.6f} degrees".format(gps.latitude))
        print("Longitude: {0:.6f} degrees".format(gps.longitude))
        print("Fix quality: {}".format(gps.fix_quality))

        if gps.satellites is not None:
            print("# satellites: {}".format(gps.satellites))
        if gps.altitude_m is not None:
            print("Altitude: {} meters".format(gps.altitude_m))
        if gps.speed_knots is not None:
            print("Speed: {} km/h".format(gps.speed_knots * 1.852))
        if gps.track_angle_deg is not None:
            print("Track angle: {} degrees".format(gps.track_angle_deg))
        if gps.horizontal_dilution is not None:
            print("Horizontal dilution: {}".format(gps.horizontal_dilution))
        if gps.height_geoid is not None:
            print("Height geoid: {} meters".format(gps.height_geoid))

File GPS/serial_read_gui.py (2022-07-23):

#!/usr/bin/env python3

# https://github.com/adafruit/Adafruit_CircuitPython_GPS/blob/main/examples/gps_simpletest.py
# read data through ttyUSB0 port
# print gps info at specified rate
# GPS set to update at 2hz
# GUI updates much faster

import time
import serial
import adafruit_gps
import PySimpleGUI as sg

uart = serial.Serial(
        # try ports ttyS0, ttyUSB0, ttyAMA0 if not working
        port='/dev/ttyUSB0',                # read/write sereal port
        baudrate = 9600,                    # data transfer: 9500 bits per second
        parity=serial.PARITY_NONE,          # no parity checking
        stopbits=serial.STOPBITS_ONE,       # indicates end of data transmission
        bytesize=serial.EIGHTBITS,          # number of data bits
        timeout=5                           # n seconds before timing out
)

gps = adafruit_gps.GPS(uart, debug=False)  # Use UART/pyserial

# setup PySimpleGUI window
sg.theme('DarkAmber')

layout = [
    [sg.Text('')], 
    [sg.Text(size=(8, 2), font=('Helvetica', 50), text_color='White', justification='center', key='speed')],
    [sg.Text(size=(8, 2), font=('Helvetica', 25), text_color='White', justification='center', key='num_satelites')],
    [sg.Text(size=(8, 2), font=('Helvetica', 25), text_color='White', justification='center', key='bat_percentage')],
    [sg.Button("Close", key='Close')]
]

window = sg.Window('GPS Demo', layout, no_titlebar=True, size=(400,800), keep_on_top=True, element_justification='c')
# window.Maximize()

# Initialize the GPS module
gps.send_command(b"PMTK314,0,1,0,1,0,0,0,0,0,0,0,0,0,0,0,0,0,0,0")  # Turn on the basic GGA and RMC info (what you typically want)
gps.send_command(b"PMTK220,1000")   # Set update rate to once a second (1hz)

# Main loop
current_speed = 0
num_satelites = 0
CONVERSION_FACTOR = 1.852       # knots to km/h
last_print = time.monotonic()
while True:

    # --------- read and update window ---------
    event, values = window.read(timeout=10)

    # --------- update GPS values ---------
    gps.update()
    current = time.monotonic()
    if current - last_print >= 1.0:
        last_print = current

    if not gps.has_fix:
        current_speed = "Weak Signal"

    if gps.satellites is not None:
        num_satelites = gps.satellites
    if gps.speed_knots is not None:
        current_speed = round(gps.speed_knots * CONVERSION_FACTOR)

    # --------- display speed in window ---------
    window['speed'].update(str(current_speed) + " km/h")
    window['num_satelites'].update("# sat: " + str(num_satelites))

    # End program if user closes window or presses the OK button
    if event == "Close" or event == sg.WIN_CLOSED:
        break

window.close()

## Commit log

2022-03-23 Start Navigation Button
2022-03-28 Settings and Battery status page - done
2022-03-28 settings and battery status pages - done
2022-03-31 fixed broken buttons
2022-06-29 gps info printing out to terminal only
2022-09-09 Adding 3D designs
    [Balljoint Top.step, Body Design v166.step, Button Board.step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]
2022-09-09 Adding README to 3D printing part
2022-10-21 Adding PCB design
    [EZhud-cm4-carrier.dsn, EZhud-cm4-carrier.kicad_pcb, EZhud-cm4-carrier.kicad_sch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]

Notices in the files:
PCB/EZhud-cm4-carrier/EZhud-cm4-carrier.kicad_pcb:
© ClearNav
